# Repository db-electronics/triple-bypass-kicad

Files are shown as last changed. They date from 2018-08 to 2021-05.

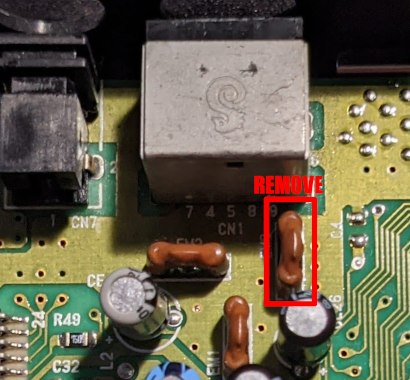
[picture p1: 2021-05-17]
Install/M2VA0 - DIN - Preview.png

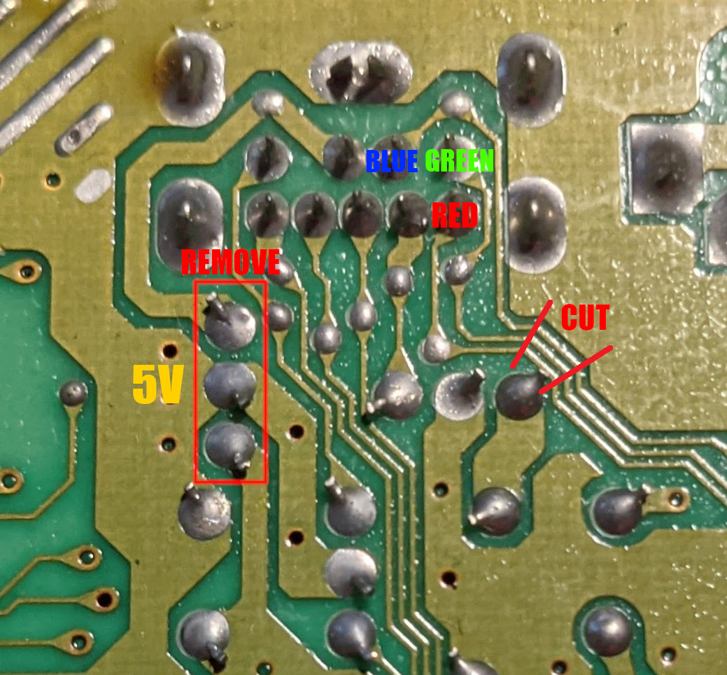
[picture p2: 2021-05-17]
Install/Gen2VA0 - DIN.png

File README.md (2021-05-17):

# Triple Bypass Version 2
This is a redesign of the fantastic 3bp from dbElectronics.  The goal of this project was to take the initial design and accommodate all models on one pcb without the need to swap parts. It was a team effort between myself, Retrorgb, and Jose Cruz who did the majorty of the testing. Ace, FirebrandX and Mobiusstriptech all were part of the group that helped with the redesign and added various ideas and suggestions that lead to the final product.  The audio adjustment work was done with the help of the mdFourier tool by Artemio Urbina found here - 
https://github.com/ArtemioUrbina/MDFourier.  Artemio and Bfbii stayed up many late nights and helped me run mdFourier to get the levels to match as close as we could to a model 1 va3 genesis.

# Installation Instructions

Currently I suggest using the Audio installation instructions from the mega amp 2.0
http://www.sega-16.com/forum/showthread.php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!

For rgb bypass instructions, please see https://www.retrorgb.com/genesistriplebypass.html for now. I will continue working on getting more up-to-date instructions.

# Confirmed Working
The current version of this is working with no issues and has been tested and measured with mdFourier. There are still some systems where the pull down jumpers have not been confirmed.  If you notice any issues, please let me know.
# Design Files
I designed this using the online software tool Easyeda. While I have made the file open for people to edit, I have not yet been able to allow for the files to be truly open source.  This is a work in progress and if I have to remake everything from scratch in Kicad. The files here will always be the most up to date versions. 
# Change Log 17/03/2020
I have added a kicad file to the folder.  it looks ok but I still see some issues with ground layers.  I am new to kicad but this pretty damn close.  As it stands, I still recommend using the current gerber files to send to a pcd fab.  The design files are good to go if you want to to change or modify the design.  
# Change Log 06/03/2020
- Changed the jumper settings on the silk screen to match new info from Jose Cruz that the model 2 va4 has all of the 75 ohm pulldowns on the Genesis. Nothing needs to be changed on the previous versions.  Just take note when installing in a model 2 va4.
# Change Log from V1
 - Added jumpers so that all pulldowns could be enabled or disabled without switching parts.
 - Added AC coupling capacitors on the input of the ths7374 to accommodate for systems that we have not measured or installed in yet.
 - Changed the op amp to a soic8 footprint to accommodate a larger variety of possible op amps.
 - Changed the op amp to a tl972 low noise op amp.
 - Lowered the overall volume and increased resistance to try and alleviate some of the clipping in the louder games.
 - Changed the resistor values and numbering to try and fit on the smaller board.
 - Changed audio and video capacitors to tantalum to accommodate for a bottom mount. 
 - Adjusted and tested installation in a model 1 Genesis. 
 - Increased the audio output capacitors to 47uf.
 - Shrunk the overall size and move the din to the middle of the board to try to avoid the power jacks on a bottom install. 
 - Changed the Low pass filter to a solder jumper that will enable when it is jumped.

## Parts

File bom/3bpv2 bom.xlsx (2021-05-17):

Name | Designator | Footprint | Quantity | Manufacturer Part | Manufacturer
5.62k | R2,R5,R4,R3 | 0603' | 4 | RK73H1JTTD5621F | KOA Speer
1.00k | R7,R8,R9,R6 | 0603' | 4 | RK73H1JTTD1001F | KOA Speer
4.7K | R10 | 0603' | 1 | RK73H1JTTD4701F | KOA Speer
75 | R11,R18,R17,R14,R13 | 0603' | 4 | RK73H1JTTDD75R0F | KOA Speer
2.20k | R1,R19,R15,R12 | 0603' | 4 | RK73H1JTTD2201F | KOA Speer
750 | R16 | 0603' | 1 | CR0603-FX-7500ELF | Bourns
210k | R20,R21,R22,R23,R24,R25 | 0603' | 6 | RK73H1JTTD2103F | KOA Speer
10K | R26,R27,R30,R33 | 0603' | 4 | RK73H1JTTD1002F | KOA Speer
330 | R36,R37 | 0603' | 2 | RK73H1JTTD3300F | KOA Speer
300K | R35,R34 | 0603' | 2 | RK73H1JTTD3003F | KOA Speer
100k | R32,R29 | 0603' | 2 | RK73H1JTTD1003F | KOA Speer
130k | R31,R28 | 0603' | 2 | CR0603-FX-1303ELF | Bourns
0.1uF/50V | C1,C2,C3,C4,C5,C6,C20 | 0603' | 7 | C0603C104M5RACTU | KEMET
22uF/10V | C7 | CP_TANTALUM_CASE-A | 1 | TAJA226K010TNJ | AVX
220uf/6.3v | C8 | CP_TANTALUM_CASE-B | 1 | TCOB0J227M8R-EN1 | ROHM Semiconductor
1uF/16V | C10,C11,C12,C13,C14,C15 | 0603' | 6 | C0603C105K4PACTU | KEMET
10uF/10V | C16,C9 | 0805' | 2 | EMK212BJ106KG-T | Taiyo Yuden
150pF/50V | C18,C19 | 0603' | 2 | CL10C151JB8NFNC | Samsung
10uF/10V | C17 | CP_TANTALUM_CASE-A | 1 | TAJA106K016RNJV | AVX
47uf/10v | C22,C21 | CP_TANTALUM_CASE-B | 2 | TAJB476M010TNJ | AVX
TL972IDR | U1 | SOIC-8 | 1 | TL972IDR | Texas Instruments
THS7374IPWR | U2 | TSSOP-14 | 1 | THS7374IPWR | Texas Instruments

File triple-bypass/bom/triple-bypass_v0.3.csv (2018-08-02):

Qty | Reference(s) | Value | Footprint | Datasheet | Description | Digikey
3 | C100, C116, C117 | 0.1uF/50V | db-smt:0603 |  | CAP CER 0.1UF 50V X7R 0603 | 445-5666-1-ND
1 | C101 | 220uF/10V | db-smt:SMD-6.6x6.6 |  | CAP ALUM 220UF 20% 10V SMD | 493-6210-1-ND
3 | C102, C109, C110 | 10uF/10V | db-smt:0805 |  | CAP CER 10UF 10V X5R 0805 | 311-1460-1-ND
6 | C103, C104, C105, C106, C107, C108 | 1uF/16V | db-smt:0603 |  | CAP CER 1UF 16V X5R 0603 | 445-1416-1-ND
2 | C111, C112 | 270pF/50V | db-smt:0603 |  | CAP CER 270PF 50V X7R 0603 | 1276-2019-1-ND
3 | C113, C114, C115 | 22uF/10V | db-smt:1206_P |  | CAP TANT 22UF 10V 10% 1206 | 478-1663-1-ND
1 | CON101 | MD-90SM | db-thparts:MD-90SM | http://www.cui.com/product/resource/digikeypdf/md-sm-series.pdf | CONN RCPT FMALE MINI DIN 9P SLDR | CP-2290-ND
1 | J101 | HDR1X2 | db-thparts:HDR1X2 |  | SIL VERTICAL PC TAIL PIN HEADER | 952-2262-ND
3 | R102, R113, R119 | 2.20k | db-smt:0603 |  | RES SMD 2.20K OHM 1% 1/10W 0603 | P2.20KHCT-ND
4 | R103, R104, R105, R106 | 5.62k | db-smt:0603 |  | RES SMD 5.62K OHM 1% 1/10W 0603 | P5.62KHCT-ND
4 | R107, R108, R109, R110 | 1.00k | db-smt:0603 |  | RES SMD 1K OHM 1% 1/10W 0603 | P1.00KHCT-ND
3 | R111, R123, R124 | 100k | db-smt:0603 |  | RES SMD 100K OHM 1% 1/10W 0603 | RHM100KAYCT-ND
5 | R112, R114, R115, R117, R118 | 75 | db-smt:0603 |  | RES 75.0 OHM 1/10W 1% 0603 SMD | P75.0HCT-ND
1 | R116 | 1.30k | db-smt:0603 |  | RES 1.30K OHM 1/10W 1% 0603 SMD | P1.30KHCT-ND
2 | R120, R127 | 6.19k | db-smt:0603 |  | RES 6.19K OHM 1/10W 1% 0603 SMD | P6.19KHCT-ND
4 | R121, R122, R125, R126 | 130k | db-smt:0603 |  | RES 130K OHM 1/10W 1% 0603 SMD | P130KHCT-ND
2 | R128, R129 | 10.0k | db-smt:0603 |  | RES 10.0K OHM 1/10W 1% 0603 SMD | P10.0KHCT-ND
2 | R130, R131 | 162k | db-smt:0603 |  | RES 162K OHM 1/10W 1% 0603 SMD | P162KHCT-ND
2 | R132, R133 | 332 | db-smt:0603 |  | RES 332 OHM 1/10W 1% 0603 SMD | P332HCT-ND
1 | U101 | THS7374IPWR | db-smt:TSSOP-14 | http://www.ti.com/lit/ds/symlink/ths7374.pdf | IC SDTV VIDEO AMP 4-CH 14-TSSOP | 296-41661-1-ND
1 | U102 | LMV358M8G-13 | db-smt:TSSOP-8_3.0mm | https://www.diodes.com/assets/Datasheets/LMV321_358.pdf | IC OPAMP GP 1MHZ RRO 8MSOP | LMV358M8G-13DITR-ND

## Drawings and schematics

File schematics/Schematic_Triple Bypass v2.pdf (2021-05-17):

+5V

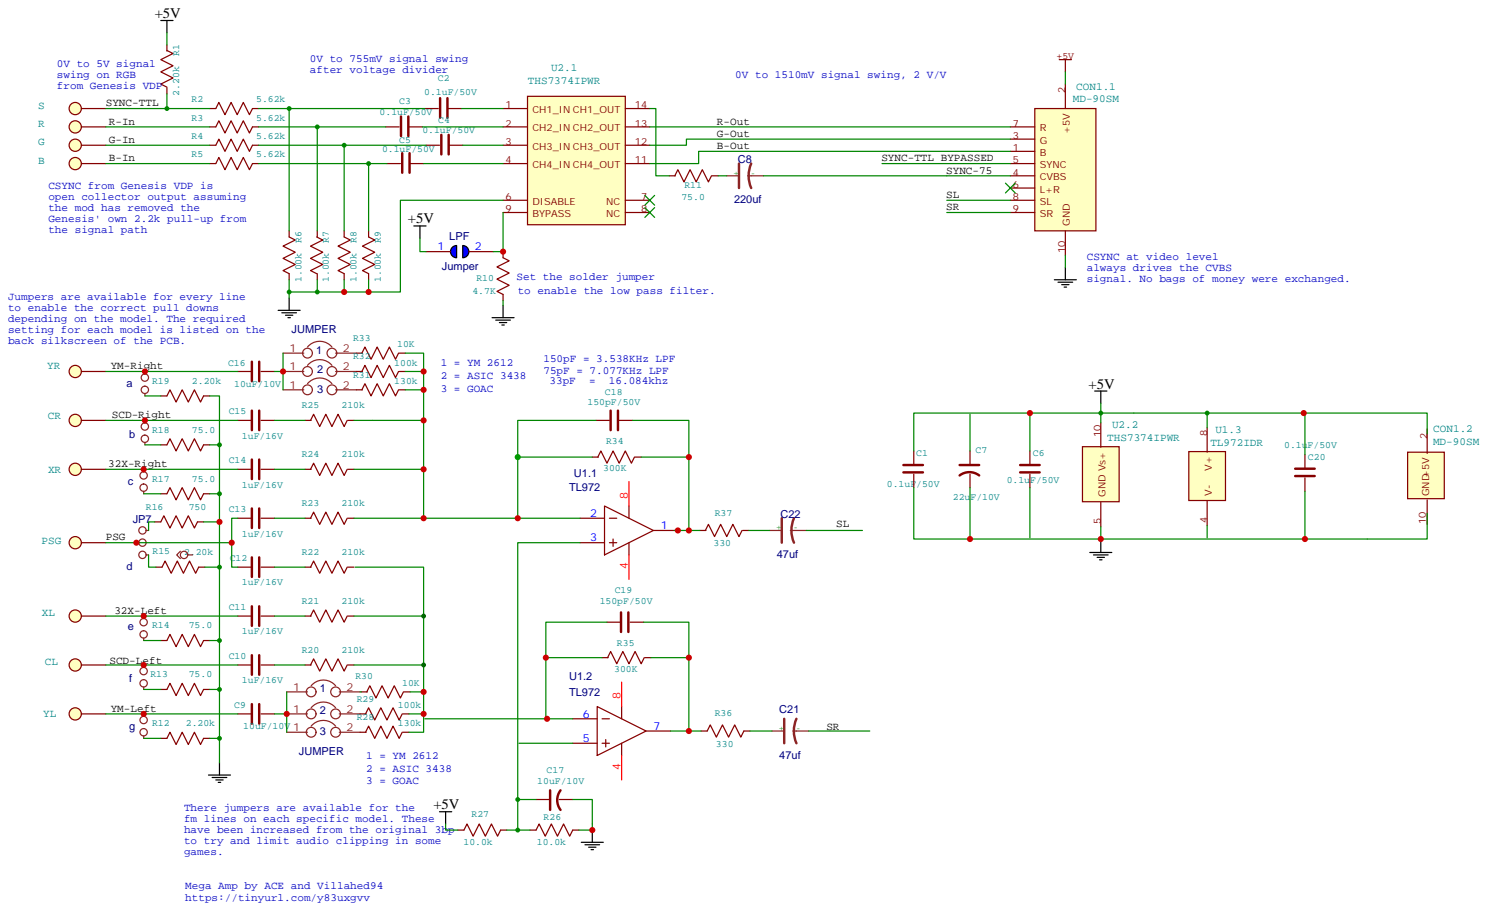
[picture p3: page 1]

CSYNC from Genesis VDP is
open collector output assuming
the mod has removed the
Genesis' own 2.2k pull-up from
the signal path

CSYNC at video level
always drives the CVBS
signal. No bags of money were exchanged.

Set the solder jumper
to enable the low pass filter.

Jumpers are available for every line
to enable the correct pull downs
depending on the model. The required
setting for each model is listed on the
back silkscreen of the PCB.

There jumpers are available for the
fm lines on each specific model. These
have been increased from the original 3bp
to try and limit audio clipping in some
games.

Mega Amp by ACE and Villahed94
https://tinyurl.com/y83uxgvv

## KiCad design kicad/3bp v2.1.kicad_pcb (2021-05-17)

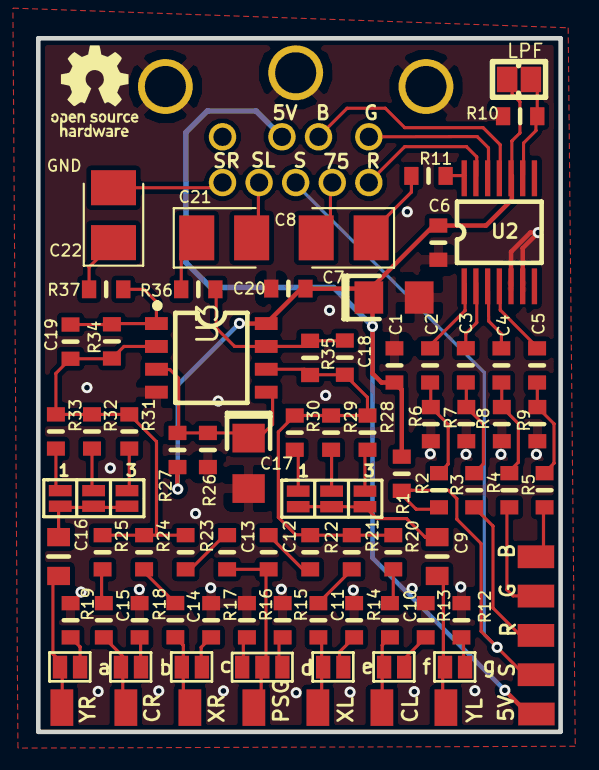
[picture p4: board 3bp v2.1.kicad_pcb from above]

Board: 2 copper layers, 29.0 x 38.5 mm, 86 parts (0 on the bottom side), 23 nets.

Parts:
1, 1#2: 3; JUMPER
5V1: TP_50; TP50
B1: TP_50; TP50
C1, C6, C20: 0.1uF/50V; 0603
C2, C3, C4, C5, C18, C19: 270pF/50V; 0603
C7, C17: 22uF/10V; 1206_P
C8, C21, C22: CP_TANTALUM_CASE-B_EIA-3528-21_REFLOW
C9, C16: 0805
C10, C11, C12, C13, C14, C15: 1uF/16V; 0603
CON1: MD-90SM
G: LOGO; OSHW-LOGO_5MM
G1: TP_50; TP50
G#2: LOGO; OSHW-LOGO_5MM
JP1: JUMPER_SOLDER_1X2
R1: TP_50; TP50
R1#2, R12, R19: 2.20k; 0603
R2, R3, R4, R5: 5.62k; 0603
R6, R7, R8, R9, R10, R11: 1.00k; 0603
R13, R14, R15, R16, R17, R18: 75.0; 0603
R20, R21, R24, R25, R29, R30: 130k; 0603
R22, R23: 100k; 0603
R26, R27: 10.0k; 0603
R28, R31, R32, R33: 6.19k; 0603
R34, R35: 162k; 0603
R36, R37: 332; 0603
S1: TP_50; TP50
SL1: TP_50; TP50
SN1: TP_50; TP50
SR2: TP_50; TP50
U2: THS7374IPWR; TSSOP-14
U3: DMP-8
XL1: TP_50; TP50
XR2: TP_50; TP50
YL1: TP_50; TP50
YR2: TP_50; TP50
a: JUMPER_PADSX2
b: JUMPER_PADSX2
c: JUMPER_PADSX2
d: JUMPER_PADSX3
e: JUMPER_PADSX2
f: JUMPER_PADSX2
g: JUMPER_PADSX2

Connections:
32X-LEFT: C11.1, C11.2, R14.1, R21.1, SL1.1, e.1, e.2
32X-RIGHT: C14.1, C14.2, R17.1, R24.1, XR2.1, c.1, c.2
+5V: 5V1.1, C1.1, C6.1, C7.1, C20.1, CON1.2, JP1.1, R1#2.2, R27.1, U2.10, U3.8
B-IN: B1.1, C5.1, C5.2, R5.1, R5.2, R9.2, U2.4
B-OUT: CON1.1, U2.11
G-IN: C4.1, C4.2, G1.1, R4.1, R4.2, R8.2, U2.3
G-OUT: CON1.3, U2.12
GND: C1.2, C6.2, C7.2, C17.2, C20.2, CON1.10, R6.1, R7.1, R8.1, R9.1, R10.1, R12.2, R13.2, R14.2, R15.2, R16.2, R17.2, R18.2, R19.2, R26.1, U2.5, U2.6, U3.4
LEFT: C18.1, C18.2, R20.2, R21.2, R22.2, R28.2, R29.2, R30.2, R35.1, R35.2, R36.2, U3.6, U3.7
LPF: JP1.2, R10.2, U2.9
PSG: C12.1, C12.2, C13.1, C13.2, R15.1, R16.1, R22.1, R23.1, SN1.1, d.1, d.2, d.3
R-IN: C3.1, C3.2, R1.1, R3.1, R3.2, R7.2, U2.2
R-OUT: CON1.7, U2.13
RIGHT: C19.1, C19.2, R23.2, R24.2, R25.2, R31.2, R32.2, R33.2, R34.1, R34.2, R37.1, U3.1, U3.2
S$33979: C17.1, R26.2, R27.2, U3.3, U3.5
SCD-LEFT: C10.1, C10.2, R13.1, R20.1, XL1.1, f.1, f.2
SCD-RIGHT: C15.1, C15.2, R18.1, R25.1, SR2.1, b.1, b.2
SL: C21.1, C21.2, CON1.8, R36.1
SR: C22.1, C22.2, CON1.9, R37.2
SYNC-75: C8.2, CON1.4
SYNC-OUT: C2.1, C2.2, C8.1, CON1.5, R1#2.1, R2.1, R2.2, R6.2, R11.1, R11.2, S1.1, U2.1, U2.14
YM-LEFT: 1.1, 1.2, C9.1, C9.2, R12.1, R28.1, R29.1, R30.1, YL1.1, g.1, g.2
YM-RIGHT: 1#2.1, 1#2.2, C16.1, C16.2, R19.1, R31.1, R32.1, R33.1, YR2.1, a.1, a.2

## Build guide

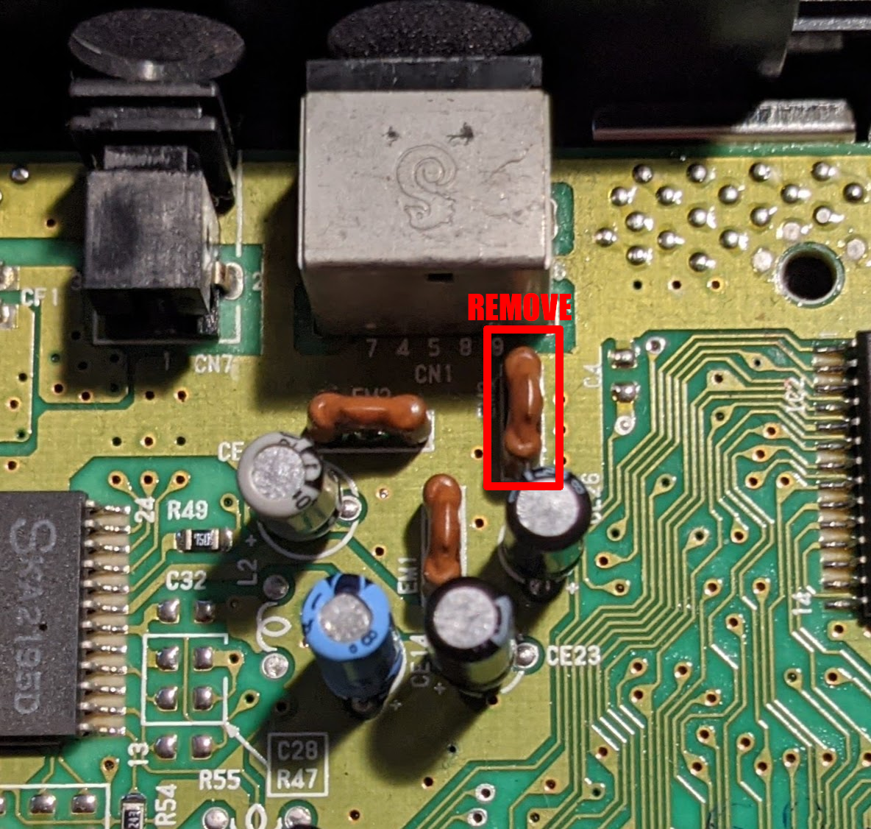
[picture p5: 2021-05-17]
Install/M2VA0 - DIN.png

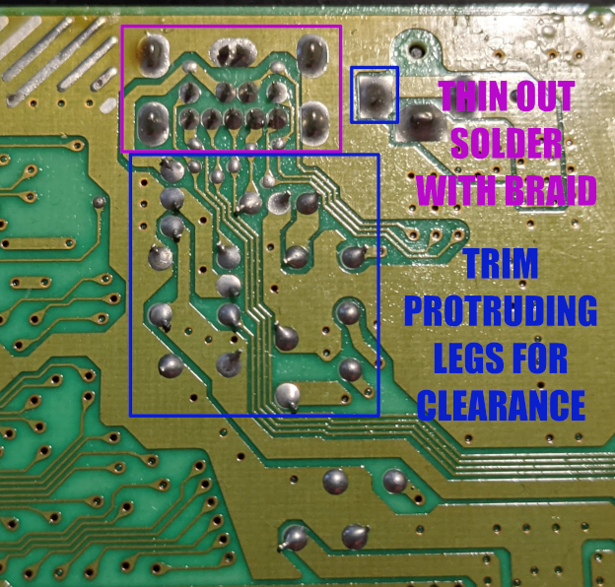
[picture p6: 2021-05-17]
Install/M2VA0 - Trimming - Preview.png

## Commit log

2018-01-24 added license
    [triple-bypass.kicad_pcb, triple-bypass.sch]
2018-01-24 building the schematic
    [triple-bypass.sch]
2018-01-26 first pass schematic done, not annotated yet
    [triple-bypass.sch]
2018-01-27 finalized and annotated schematic, waiting for review
    [triple-bypass.sch]
2018-08-01 added parts to PCB
    [triple-bypass.kicad_pcb, triple-bypass.sch]
2018-08-01 more parts placement
    [triple-bypass.kicad_pcb, triple-bypass.sch]
2018-08-01 v0.3 prelim routing complete, sch added
    [triple-bypass.kicad_pcb, triple-bypass.sch]
2018-08-02 changed csync routing to pins 1/14 on 7374
    [triple-bypass.kicad_pcb, triple-bypass.sch, triple-bypass_v0.3.csv]
2018-08-07 Update to Mega Amp 2.0 and generated 3 seperated BOMs/SCH
    [triple-bypass-B.Cu.gbl, triple-bypass-B.Mask.gbs, triple-bypass-B.SilkS.gbo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]
2018-10-11 fixed R116 in BOM - 2.20k instead of 1.30k
    [triple-bypass_asic-ym3438_v0.3.csv, triple-bypass_goac-ym3438_v0.3.csv, triple-bypass_ym2612_v0.3.csv]
2018-11-12 fixed BOM mistake - R123,R124 changed to 75.0k on YM3438-GOAC version
    [triple-bypass_goac-ym3438_v0.3.csv]
2020-03-05 Create Schematics
2020-03-26 Better version with ground connected
    [3bp v2.1.kicad_pcb]

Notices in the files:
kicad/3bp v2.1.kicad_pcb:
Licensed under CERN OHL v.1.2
